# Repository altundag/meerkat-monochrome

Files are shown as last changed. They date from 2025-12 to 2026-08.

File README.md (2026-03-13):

# Meerkat Monochrome

Meerkat Monochrome is a monochrome camera project that I started as a hobby. This repository contains the complete design, including PCB layouts, firmware, and supporting tools. The camera hardware consists of:
- an MT9M001C12STM monochrome image sensor
- an RP2354A used as the camera's processing and control unit
- an APS6404L-3SQR QSPI PSRAM for the frame buffer
- an FM25L16B F-RAM to permanently store data (e.g., the frame count)

The image sensor itself is capable of operating at clock speeds up to 48 MHz. However, in this design the pixel clock is set to 6.5 MHz, because the PSRAM frame buffer cannot accept data at higher throughput. This also means the project doesn't require a high-speed PCB, which makes my job easier since I'm not a professional PCB designer.
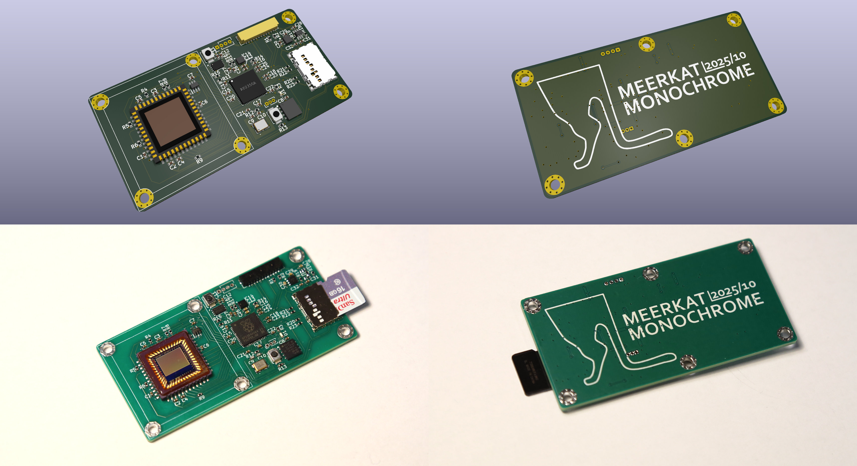
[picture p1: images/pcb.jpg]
PCB Prototype Image PCB Prototype


The PCB design has tiny 0402 components. They require a steady hand, but you can still assemble the board manually using a reflow oven.

The firmware is written entirely in Rust and is actively under development. When this project started, there was no Rust library available to interface with the MT9M001C12STM sensor, so this repository also incleads a tool that automatically generates a library from a JSON sensor description file. Please see the `mt9m001` project for details.

# Examples

An example image taken during prototype PCB testing:

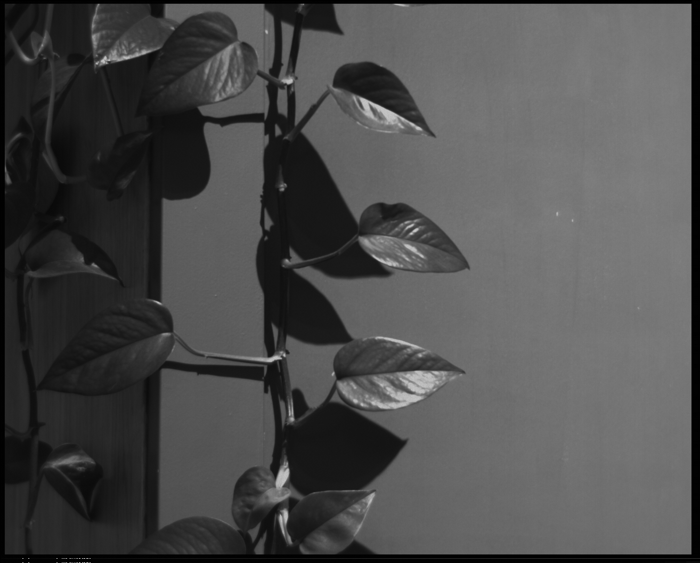
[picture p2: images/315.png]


If you have a close look at the image above, you can see the fixed pattern noise. It is more visible when the sensor is evenly exposed to light.

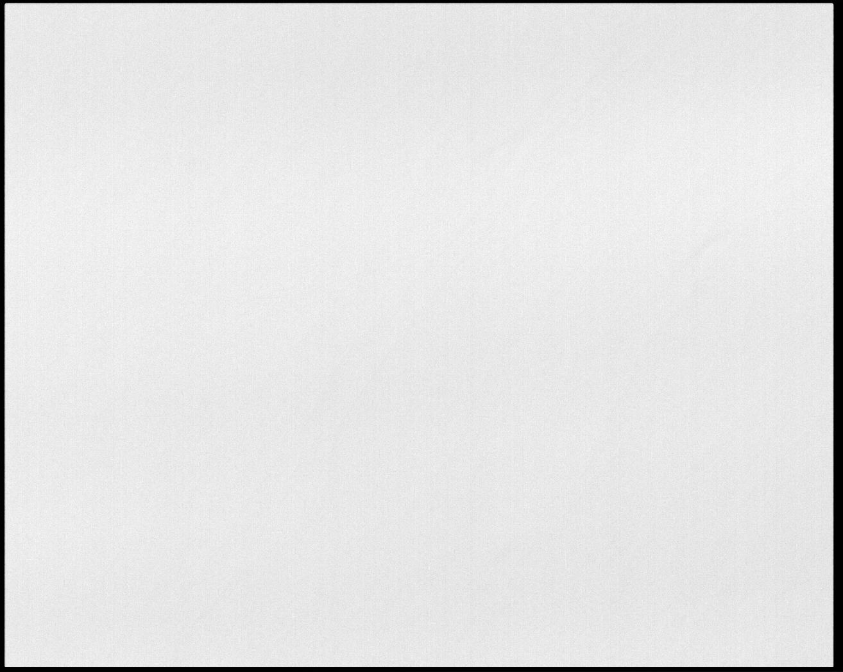
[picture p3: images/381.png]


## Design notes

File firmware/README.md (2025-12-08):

# Meerkat Firmware

## Build and Run

To build and run the firmware, first install Rust, then add the `thumbv8m.main-none-eabihf` target:

```shell
rustup target add thumbv8m.main-none-eabihf
```

NExt, make the [picotool executable](https://github.com/raspberrypi/pico-sdk-tools/releases) available in your system's environment path. Once that's done, run:

```shell
cargo run --release
```

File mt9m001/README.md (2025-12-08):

# MT9M001C12STM

An automatically generated Rust library to control MT9M001C12STM image sensors.

## Generation

Run the following command to generate the library from the JSON description file.

```shell
python .\generator.py .\mt9m001.json .\src\lib.rs
```

The generator implementation is primitive and may produce code with minor `clippy` issues. Run the following command to automatically fix them.

```shell
cargo clippy --fix --allow-dirty
```

## Sensor Description File

The expected sensor description file is a simple JSON file that:
- contains the sensor name and address
- list the registers, their documentation, and their bit-fields (if any)

See the `mt9m001.json` file for an examples.

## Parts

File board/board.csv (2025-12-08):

Reference | Qty | Value | DNP | Exclude from BOM | Exclude from Board | Footprint | Datasheet
C1,C2,C3,C4,C5,C6,C7,C8,C11,C15,C18,C19,C20,C21,C22,C23,C24,C25,C26,C27,C31 | 21 | 100n |  |  |  | Capacitor_SMD:C_0402_1005Metric | ~
C9,C10 | 2 | 15p |  |  |  | Capacitor_SMD:C_0402_1005Metric | ~
C12,C32 | 2 | 1u |  |  |  | Capacitor_SMD:C_0402_1005Metric | ~
C13,C14 | 2 | 4.7u |  |  |  | components:C_0402_1005Metric_small_pads | ~
C16,C17,C28,C29,C30 | 5 | 4.7u |  |  |  | Capacitor_SMD:C_0402_1005Metric | ~
D1 | 1 | LED |  |  |  | LED_SMD:LED_0402_1005Metric | ~
D2 | 1 | LM66100DCKR |  |  |  | components:LM66100DCKR | http://www.ti.com/lit/gpn/LM66100
H1,H2 | 2 | MountingHole_Pad |  | Excluded from BOM |  | MountingHole:MountingHole_2.2mm_M2_Pad_Via | ~
IC1 | 1 | NC7SZ11P6X |  |  |  | components:NC7SZ11P6X | https://www.onsemi.com/pub/Collateral/NC7SZ11-D.PDF
IC2 | 1 | FM25L16B-DG |  |  |  | components:FM25L16B-DG | http://www.cypress.com/file/136516/download
IC3 | 1 | NCP189CMTW330TAG |  |  |  | components:NCP189CMTW330TAG | https://www.onsemi.com/pub/Collateral/NCP189-D.PDF
J1 | 1 | USB |  |  |  | Connector_PinHeader_1.27mm:PinHeader_1x04_P1.27mm_Vertical | ~
J2 | 1 | Conn_01x12 |  |  |  | Connector_Hirose:Hirose_DF52-12S-0.8H_1x12-1MP_P0.80mm_Horizontal | ~
J3 | 1 | Conn_01x03 |  |  |  | Connector_PinHeader_1.00mm:PinHeader_1x03_P1.00mm_Vertical | ~
J4 | 1 | MEM2085-00-115-00-A |  |  |  | components:MEM20850011500A | https://gct.co/files/drawings/mem2085.pdf
L1 | 1 | 3.3u |  |  |  | components:AOTA-B201610S3R3-101-T | ~
M1 | 1 | ~ |  |  |  | components:c-mount-03
R1,R4,R5,R6,R18 | 5 | 10K |  |  |  | Resistor_SMD:R_0402_1005Metric | ~
R2 | 1 | 100R |  |  |  | Resistor_SMD:R_0402_1005Metric | ~
R3 | 1 | 65R |  |  |  | Resistor_SMD:R_0402_1005Metric | ~
R7,R8 | 2 | 1.5K |  |  |  | Resistor_SMD:R_0402_1005Metric | ~
R9 | 1 | 30R |  |  |  | Resistor_SMD:R_0402_1005Metric | ~
R11 | 1 | 100K |  |  |  | components:R_0402_1005Metric_small_pads | ~
R12,R13 | 2 | 1k |  |  |  | Resistor_SMD:R_0402_1005Metric | ~
R14 | 1 | 33 |  |  |  | Resistor_SMD:R_0402_1005Metric | ~
R15 | 1 | 1k |  |  |  | components:R_0402_1005Metric_small_pads | ~
R16,R17 | 2 | 27 |  |  |  | Resistor_SMD:R_0402_1005Metric | ~
R19 | 1 | 0R |  |  |  | components:R_0402_1005Metric_small_pads | ~
R20,R21,R22,R23 | 4 | 10K |  |  |  | components:R_0402_1005Metric_small_pads | ~
SW1,SW2 | 2 | SW_Push |  |  |  | Button_Switch_SMD:SW_SPST_B3U-1000P | ~
U1 | 1 | MT9M001C12STM |  |  |  | components:MT9M001C12STM
U2 | 1 | APS6404L-3SQR-ZR |  |  |  | Package_SON:Winbond_USON-8-1EP_3x2mm_P0.5mm_EP0.2x1.6mm | https://www.mouser.com/datasheet/2/1127/APM_PSRAM_QSPI_APS6404L_3SQR_v2_3_PKG-1954826.pdf
U3 | 1 | RP2350_60QFN |  |  |  | components:RP2350-QFN-60-1EP_7x7_P0.4mm_EP3.4x3.4mm_ThermalVias
Y1 | 1 | ABM8-272-T3 |  |  |  | components:ABM8272T3 | ~

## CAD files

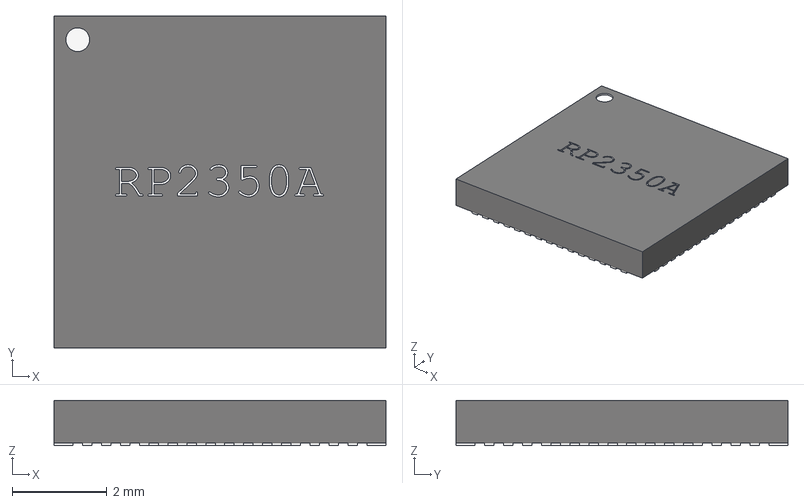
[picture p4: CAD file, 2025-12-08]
board/components/RP2350-QFN-60.step
7.00 x 7.00 x 0.95 mm

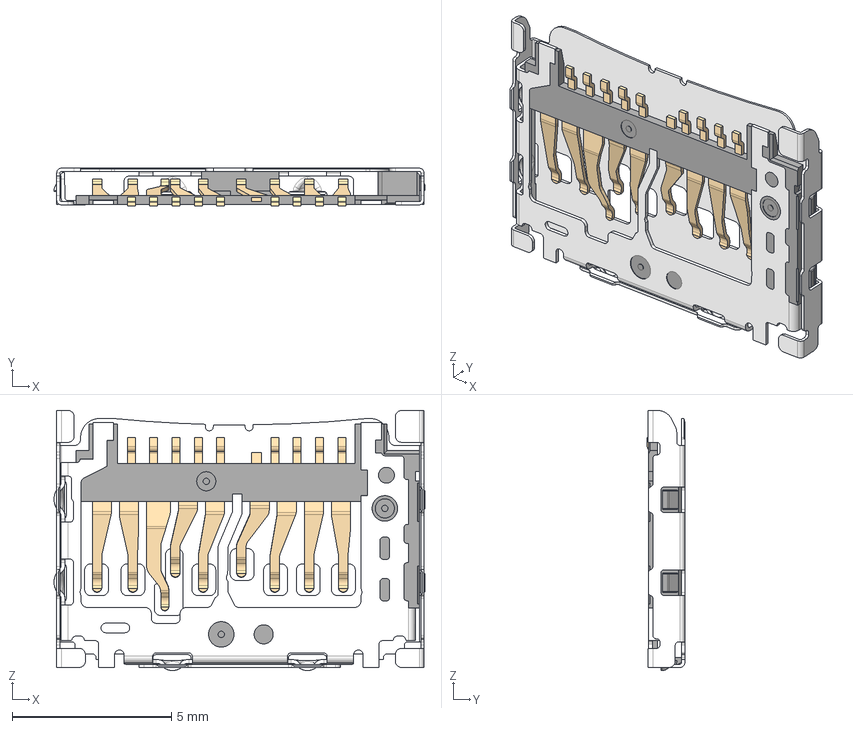
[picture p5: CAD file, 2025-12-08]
board/components/MEM2085-00-115-00-A.stp
11.6 x 1.18 x 8.16 mm
MEM2085-00-115-00-A_PART3
MEM2085-00-115-00-A_PART2
MEM2085-00-115-00-A_PART1

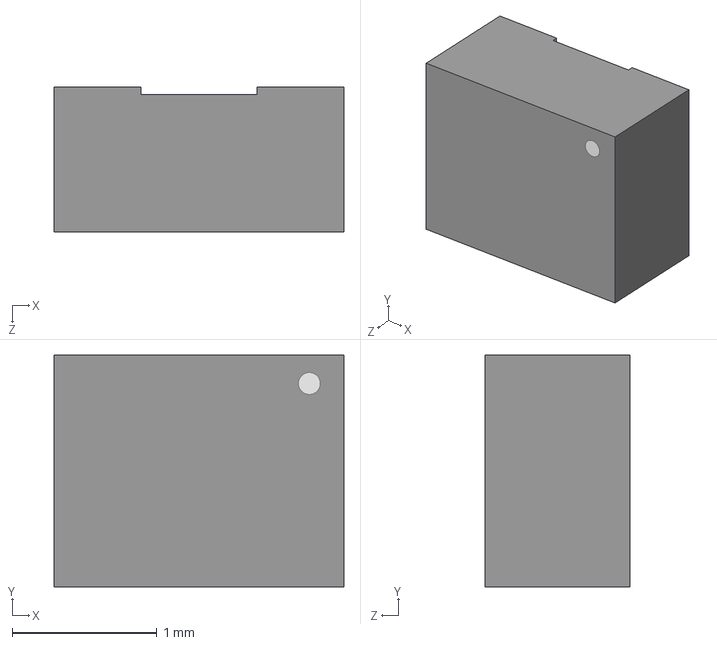
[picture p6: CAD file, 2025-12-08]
board/components/AOTA-B201610S3R3-101-T.stp
2.00 x 1.60 x 1.00 mm

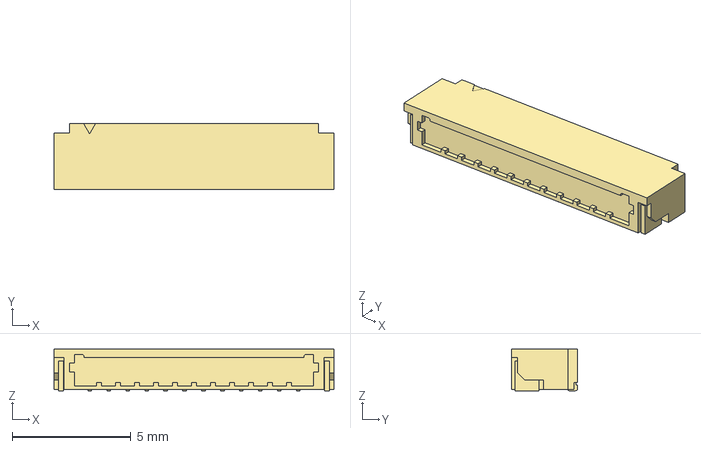
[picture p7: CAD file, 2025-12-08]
board/components/DF52-12S-0.8H_21_.stp
11.8 x 2.77 x 1.75 mm

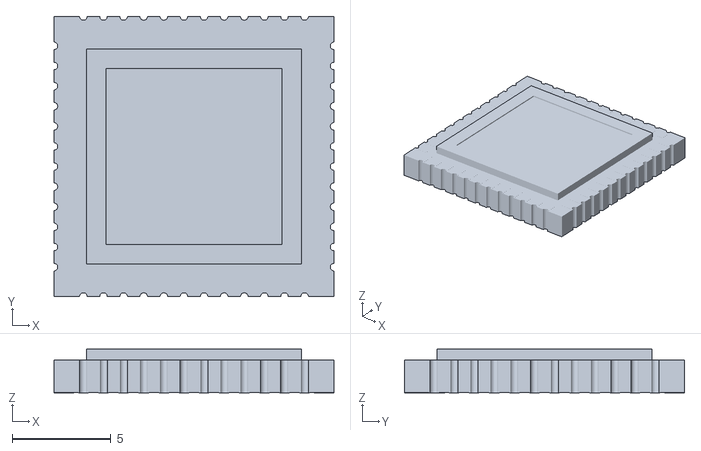
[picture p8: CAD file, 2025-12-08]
board/components/MT9M001C12STM.obj
14.2 x 14.2 x 2.21

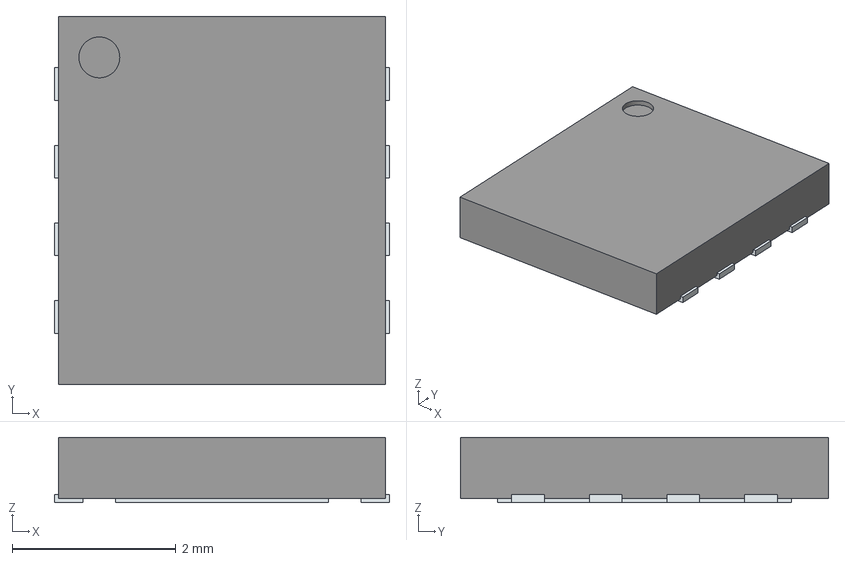
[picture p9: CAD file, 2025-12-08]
board/components/FM25L16B-DG.stp
4.10 x 4.50 x 0.8 mm
ThermalPin
PinsArrayLR

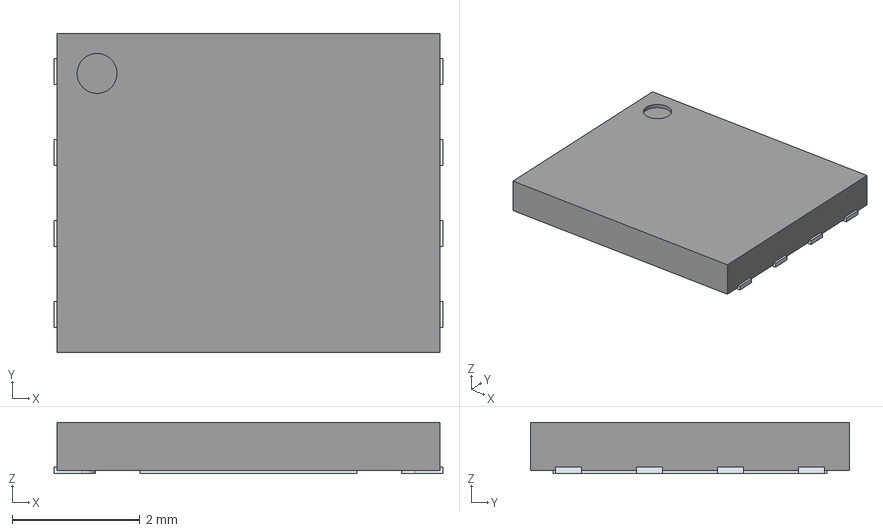
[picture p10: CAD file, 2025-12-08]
board/components/W25Q128JVPIQ.stp
6.10 x 5.00 x 0.8 mm
ThermalPin
PinsArrayLR

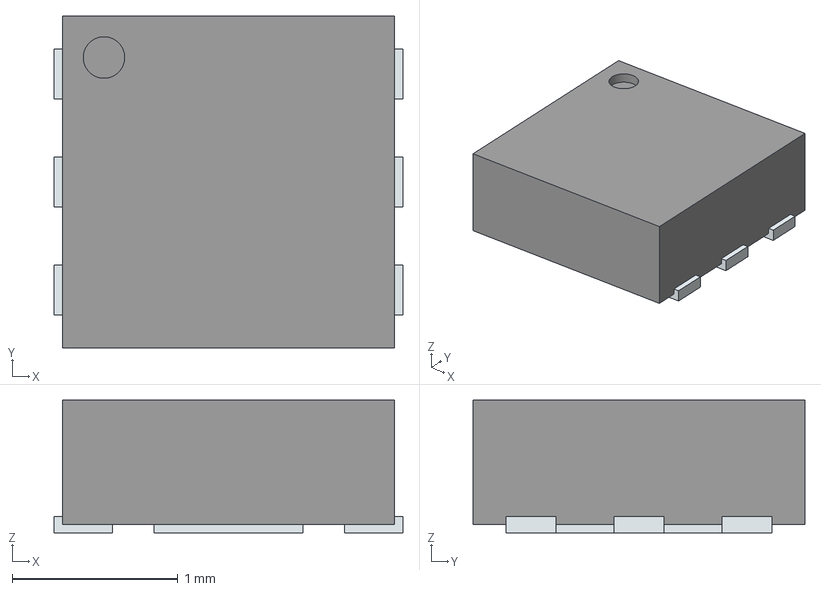
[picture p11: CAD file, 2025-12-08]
board/components/NCP189CMTW330TAG.stp
2.10 x 2.00 x 0.8 mm
ThermalPin
PinsArrayLR

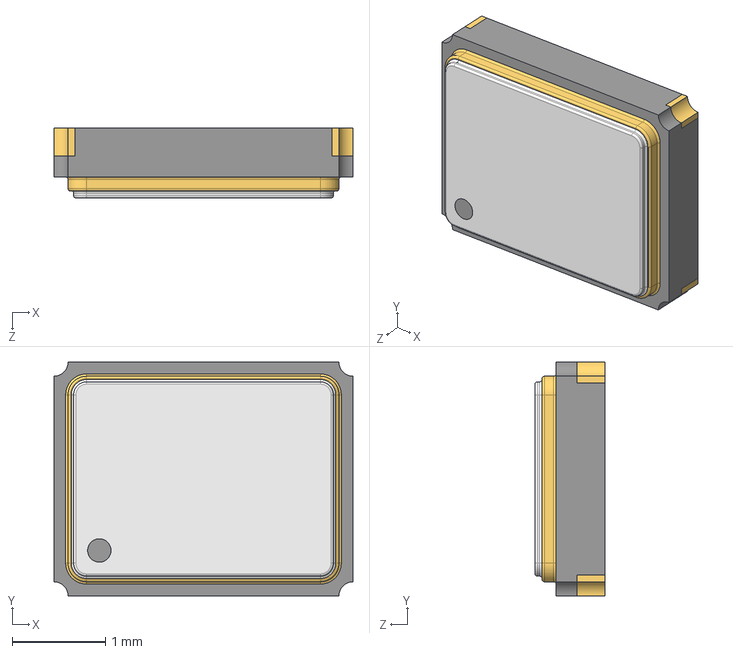
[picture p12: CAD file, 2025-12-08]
board/components/ABM8-272-T3.stp
3.20 x 2.50 x 0.75 mm

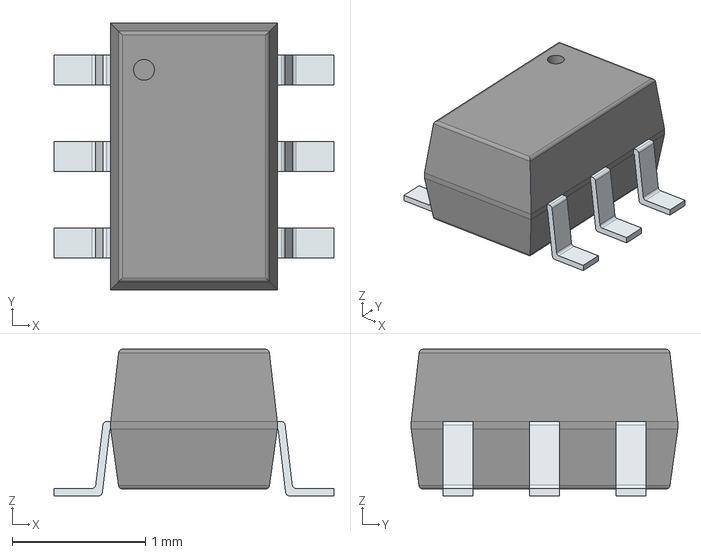
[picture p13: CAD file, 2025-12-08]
board/components/NC7SZ11P6X.stp
2.10 x 2.00 x 1.10 mm
PinsArrayLR

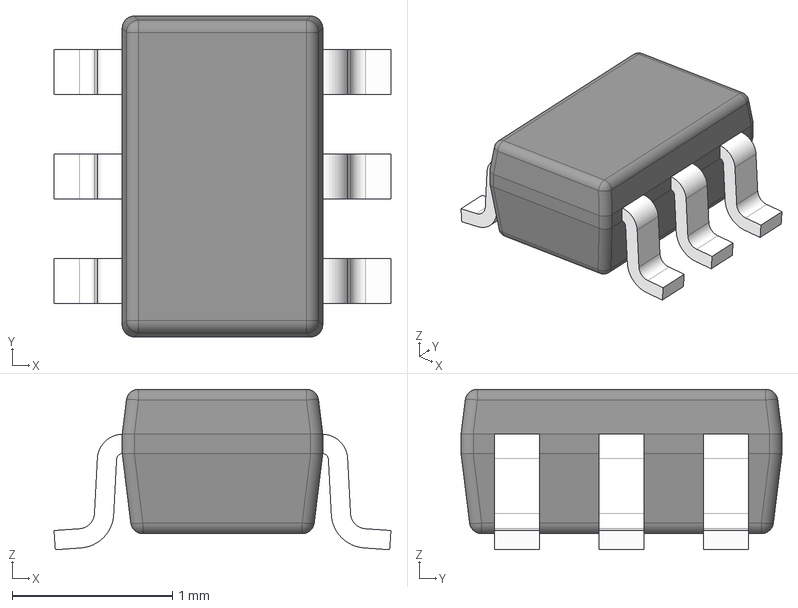
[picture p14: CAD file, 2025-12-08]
board/components/LM66100DCKR.stp
2.10 x 2.00 x 1.00 mm
BODY-SOT
LEAD-SOT x 6
PIN1-ID

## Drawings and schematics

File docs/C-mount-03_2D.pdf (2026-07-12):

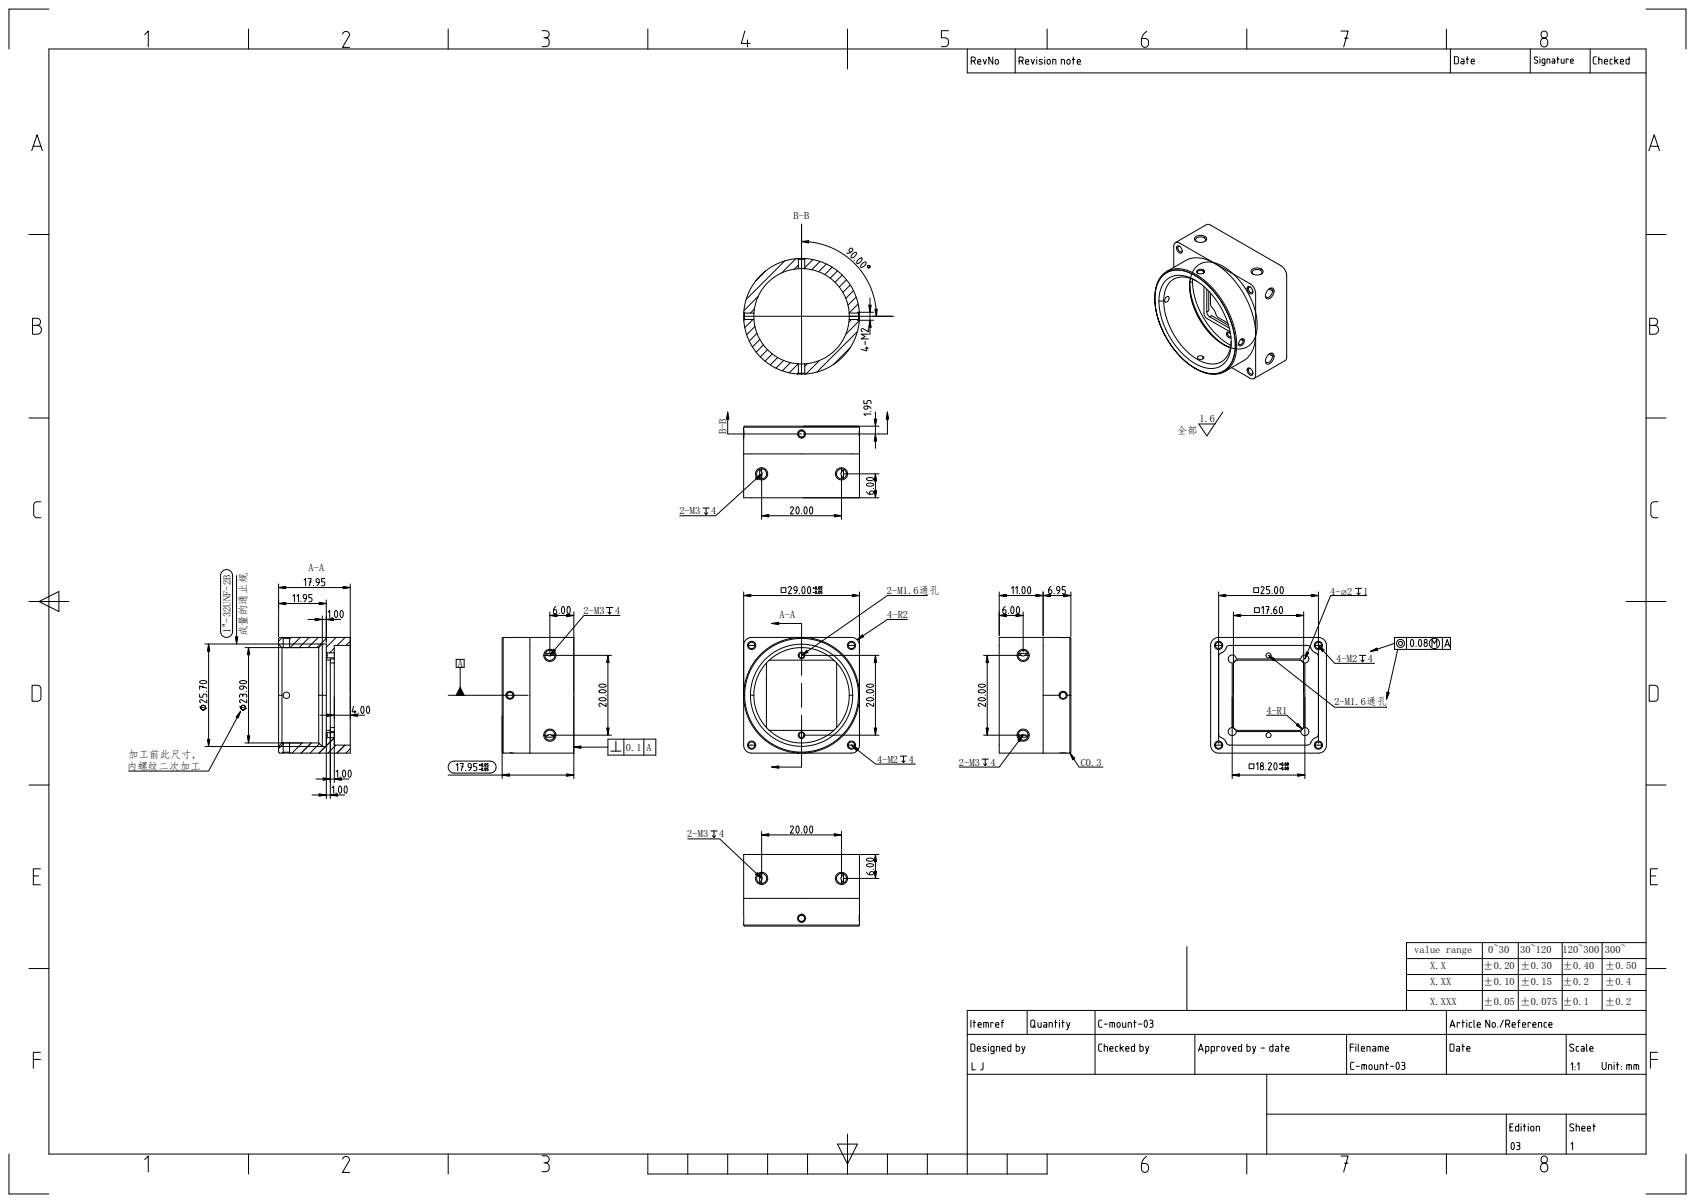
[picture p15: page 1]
A 加工前此尺寸, 内螺纹二次加工; 1"-32UNF-2B 成量的通止规

value range | 0~30 | 30~120 | 120~300 | 300~
X.X | ±0.20 | ±0.30 | ±0.40 | ±0.50
X.XX | ±0.10 | ±0.15 | ±0.2 | ±0.4
X.XXX | ±0.05 | ±0.075 | ±0.1 | ±0.2

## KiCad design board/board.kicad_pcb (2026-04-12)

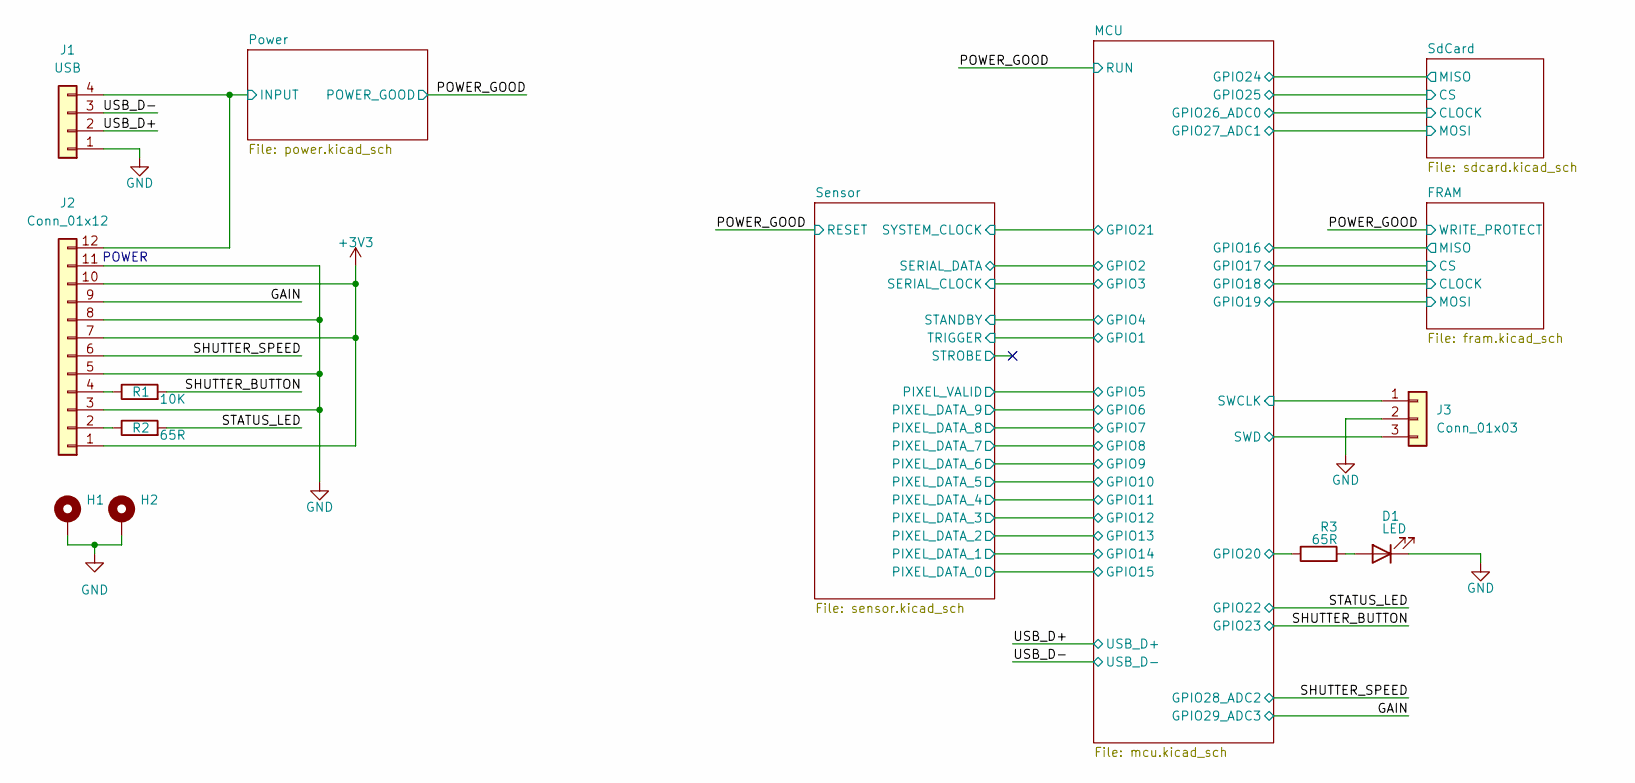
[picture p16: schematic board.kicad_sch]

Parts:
D1: LED; LED_0402_1005Metric
H1, H2: MountingHole_Pad; MountingHole_2.2mm_M2_Pad_Via
J1: USB; PinHeader_1x04_P1.27mm_Vertical
J2: Conn_01x12; Hirose_DF52-12S-0.8H_1x12-1MP_P0.80mm_Horizontal
J3: Conn_01x03; PinHeader_1x03_P1.00mm_Vertical
R1: 10K; R_0402_1005Metric
R2, R3: 65R; R_0402_1005Metric

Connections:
+3V3: J2.1, J2.7, J2.10; also elsewhere on the board
/GAIN: J2.9; also elsewhere on the board
/MCU/GPIO20: R3.1; also elsewhere on the board
/MCU/SWCLK: J3.1; also elsewhere on the board
/MCU/SWD: J3.3; also elsewhere on the board
/Power/INPUT: J1.4, J2.12; also elsewhere on the board
/SHUTTER_BUTTON: R1.2; also elsewhere on the board
/SHUTTER_SPEED: J2.6; also elsewhere on the board
/STATUS_LED: R2.2; also elsewhere on the board
/USB_D+: J1.2; also elsewhere on the board
/USB_D-: J1.3; also elsewhere on the board
GND: D1.1 (K), H1.1, H2.1, J1.1, J2.3, J2.5, J2.8, J2.11, J3.2; also elsewhere on the board
unnamed: D1.2 (A), R3.2
unnamed: J2.2, R2.1
unnamed: J2.4, R1.1

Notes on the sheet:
POWER

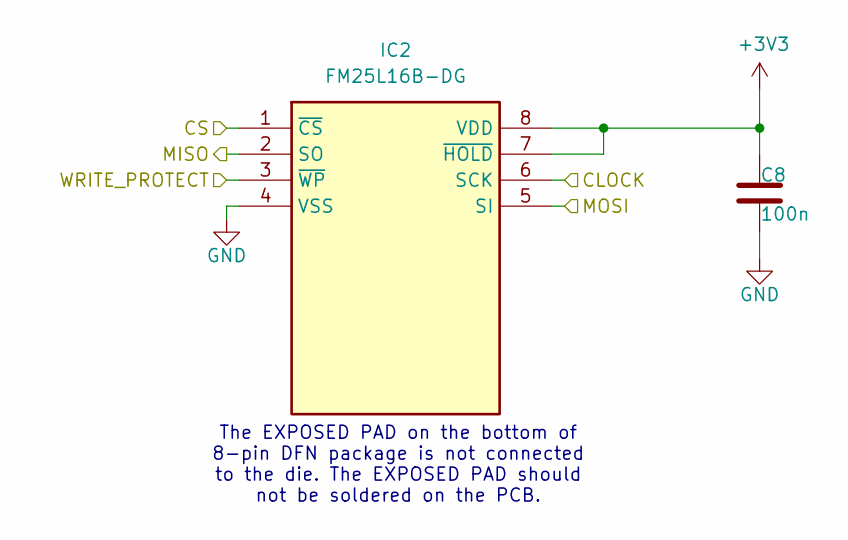
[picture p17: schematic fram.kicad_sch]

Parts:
C8: 100n; C_0402_1005Metric
IC2: FM25L16B-DG; Mouser Part Number 877-FM25L16B-DG

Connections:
+3V3: C8.2, IC2.7 (~HOLD), IC2.8 (VDD); also elsewhere on the board
/FRAM/CLOCK: IC2.6 (SCK); also elsewhere on the board
/FRAM/CS: IC2.1 (~CS); also elsewhere on the board
/FRAM/MISO: IC2.2 (SO); also elsewhere on the board
/FRAM/MOSI: IC2.5 (SI); also elsewhere on the board
/POWER_GOOD: IC2.3 (~WP); also elsewhere on the board
GND: C8.1, IC2.4 (VSS); also elsewhere on the board

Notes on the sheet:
The EXPOSED PAD on the bottom of 8-pin DFN package is not connected to the die. The EXPOSED PAD should not be soldered on the PCB.

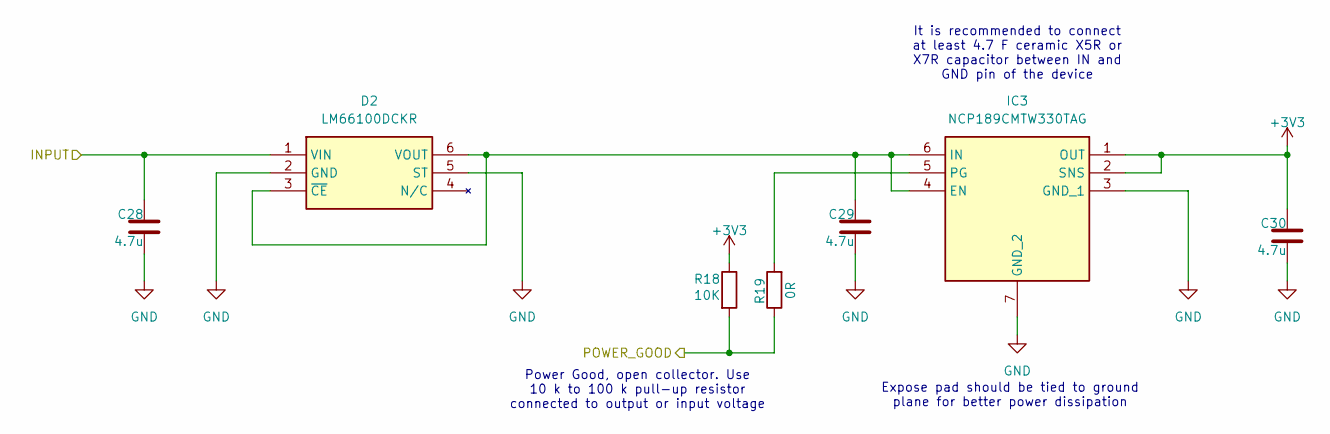
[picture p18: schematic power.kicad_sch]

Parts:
C28, C29, C30: 4.7u; C_0402_1005Metric
D2: LM66100DCKR; Mouser Part Number 595-LM66100DCKR
IC3: NCP189CMTW330TAG; Mouser Part Number 863-NCP189CMTW330TAG
R18: 10K; R_0402_1005Metric
R19: 0R; R_0402_1005Metric_small_pads

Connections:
+3V3: C30.2, IC3.1 (OUT), IC3.2 (SNS), R18.1; also elsewhere on the board
/POWER_GOOD: R18.2, R19.1; also elsewhere on the board
/Power/INPUT: C28.2, D2.1 (VIN); also elsewhere on the board
GND: C28.1, C29.1, C30.1, D2.2 (GND), D2.5 (ST), IC3.3 (GND_1), IC3.7 (GND_2); also elsewhere on the board
unnamed: C29.2, D2.3 (~CE), D2.6 (VOUT), IC3.4 (EN), IC3.6 (IN)
unnamed: IC3.5 (PG), R19.2

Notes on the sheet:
Power Good, open collector. Use 10 k to 100 k pull−up resistor connected to output or input voltage
It is recommended to connect at least 4.7 F ceramic X5R or X7R capacitor between IN and GND pin of the device
Expose pad should be tied to ground plane for better power dissipation

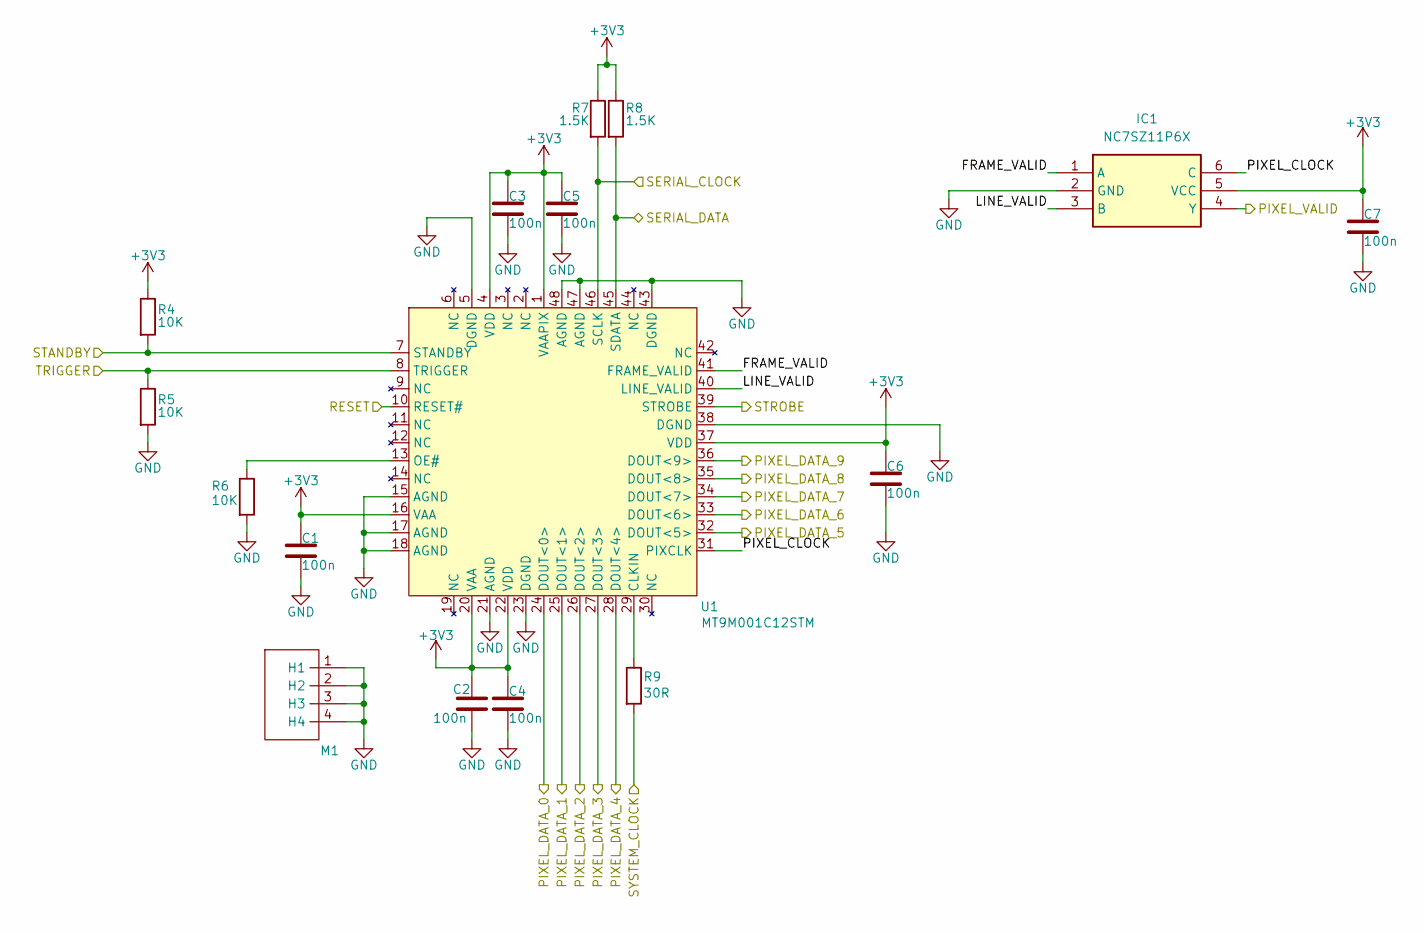
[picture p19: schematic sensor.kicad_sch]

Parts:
C1, C2, C3, C4, C5, C6, C7: 100n; C_0402_1005Metric
IC1: NC7SZ11P6X; Mouser Part Number 512-NC7SZ11P6X
M1: c-mount-03
R4, R5, R6: 10K; R_0402_1005Metric
R7, R8: 1.5K; R_0402_1005Metric
R9: 30R; R_0402_1005Metric
U1: MT9M001C12STM

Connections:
+3V3: C1.2, C2.2, C3.2, C4.2, C5.2, C6.2, C7.2, IC1.5 (VCC), R4.1, R7.1, R8.1, U1.1 (VAAPIX), U1.4 (VDD), U1.16 (VAA), U1.20 (VAA), U1.22 (VDD), U1.37 (VDD); also elsewhere on the board
/MCU/GPIO1: R5.1, U1.8 (TRIGGER); also elsewhere on the board
/MCU/GPIO2: R8.2, U1.45 (SDATA); also elsewhere on the board
/MCU/GPIO3: R7.2, U1.46 (SCLK); also elsewhere on the board
/MCU/GPIO4: R4.2, U1.7 (STANDBY); also elsewhere on the board
/MCU/GPIO5: IC1.4 (Y); also elsewhere on the board
/MCU/GPIO6: U1.36 (DOUT<9>); also elsewhere on the board
/MCU/GPIO7: U1.35 (DOUT<8>); also elsewhere on the board
/MCU/GPIO8: U1.34 (DOUT<7>); also elsewhere on the board
/MCU/GPIO9: U1.33 (DOUT<6>); also elsewhere on the board
/MCU/GPIO10: U1.32 (DOUT<5>); also elsewhere on the board
/MCU/GPIO11: U1.28 (DOUT<4>); also elsewhere on the board
/MCU/GPIO12: U1.27 (DOUT<3>); also elsewhere on the board
/MCU/GPIO13: U1.26 (DOUT<2>); also elsewhere on the board
/MCU/GPIO14: U1.25 (DOUT<1>); also elsewhere on the board
/MCU/GPIO15: U1.24 (DOUT<0>); also elsewhere on the board
/MCU/GPIO21: R9.2; also elsewhere on the board
/POWER_GOOD: U1.10 (RESET#); also elsewhere on the board
/Sensor/FRAME_VALID: IC1.1 (A), U1.41 (FRAME_VALID)
/Sensor/LINE_VALID: IC1.3 (B), U1.40 (LINE_VALID)
/Sensor/PIXEL_CLOCK: IC1.6 (C), U1.31 (PIXCLK)
/Sensor/STROBE: U1.39 (STROBE)
GND: C1.1, C2.1, C3.1, C4.1, C5.1, C6.1, C7.1, IC1.2 (GND), M1.1 (H1), M1.2 (H2), M1.3 (H3), M1.4 (H4), R5.2, R6.2, U1.5 (DGND), U1.15 (AGND), U1.17 (AGND), U1.18 (AGND), U1.21 (AGND), U1.23 (DGND), U1.38 (DGND), U1.43 (DGND), U1.47 (AGND), U1.48 (AGND); also elsewhere on the board
unnamed: R9.1, U1.29 (CLKIN)
unnamed: R6.1, U1.13 (OE#)

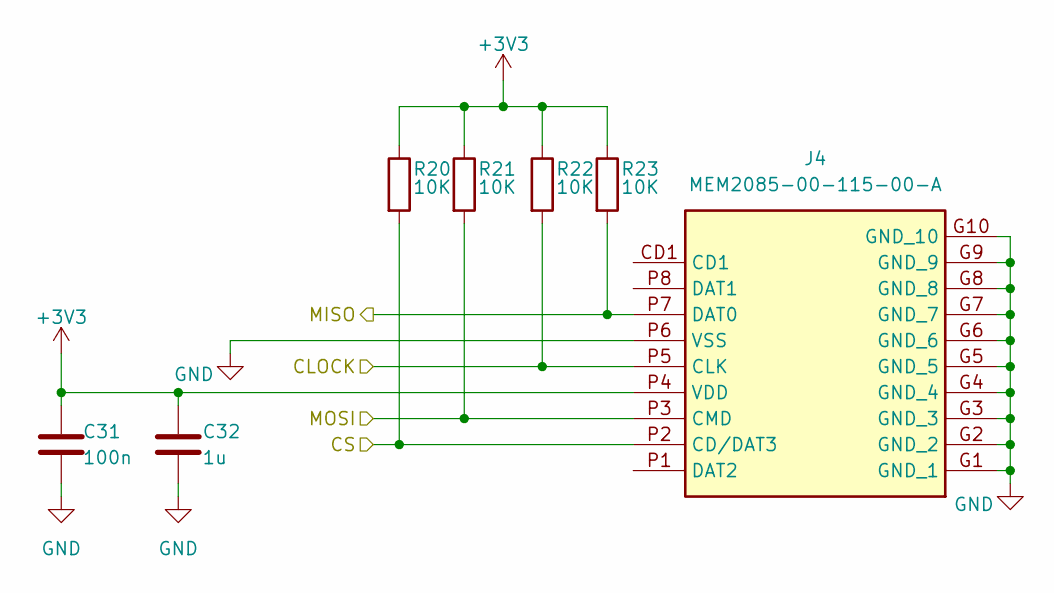
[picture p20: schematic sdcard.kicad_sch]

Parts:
C31: 100n; C_0402_1005Metric
C32: 1u; C_0402_1005Metric
J4: MEM2085-00-115-00-A; MEM20850011500A; Mouser Part Number 640-MEM20850011500A
R20, R21, R22, R23: 10K; R_0402_1005Metric_small_pads

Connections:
+3V3: C31.2, C32.2, J4.P4 (VDD), R20.1, R21.1, R22.1, R23.1; also elsewhere on the board
/MCU/GPIO24: J4.P7 (DAT0), R23.2; also elsewhere on the board
/MCU/GPIO25: J4.P2 (CD/DAT3), R20.2; also elsewhere on the board
/MCU/GPIO26_ADC0: J4.P5 (CLK), R22.2; also elsewhere on the board
/MCU/GPIO27_ADC1: J4.P3 (CMD), R21.2; also elsewhere on the board
GND: C31.1, C32.1, J4.G1 (GND_1), J4.G2 (GND_2), J4.G3 (GND_3), J4.G4 (GND_4), J4.G5 (GND_5), J4.G6 (GND_6), J4.G7 (GND_7), J4.G8 (GND_8), J4.G9 (GND_9), J4.G10 (GND_10), J4.P6 (VSS); also elsewhere on the board

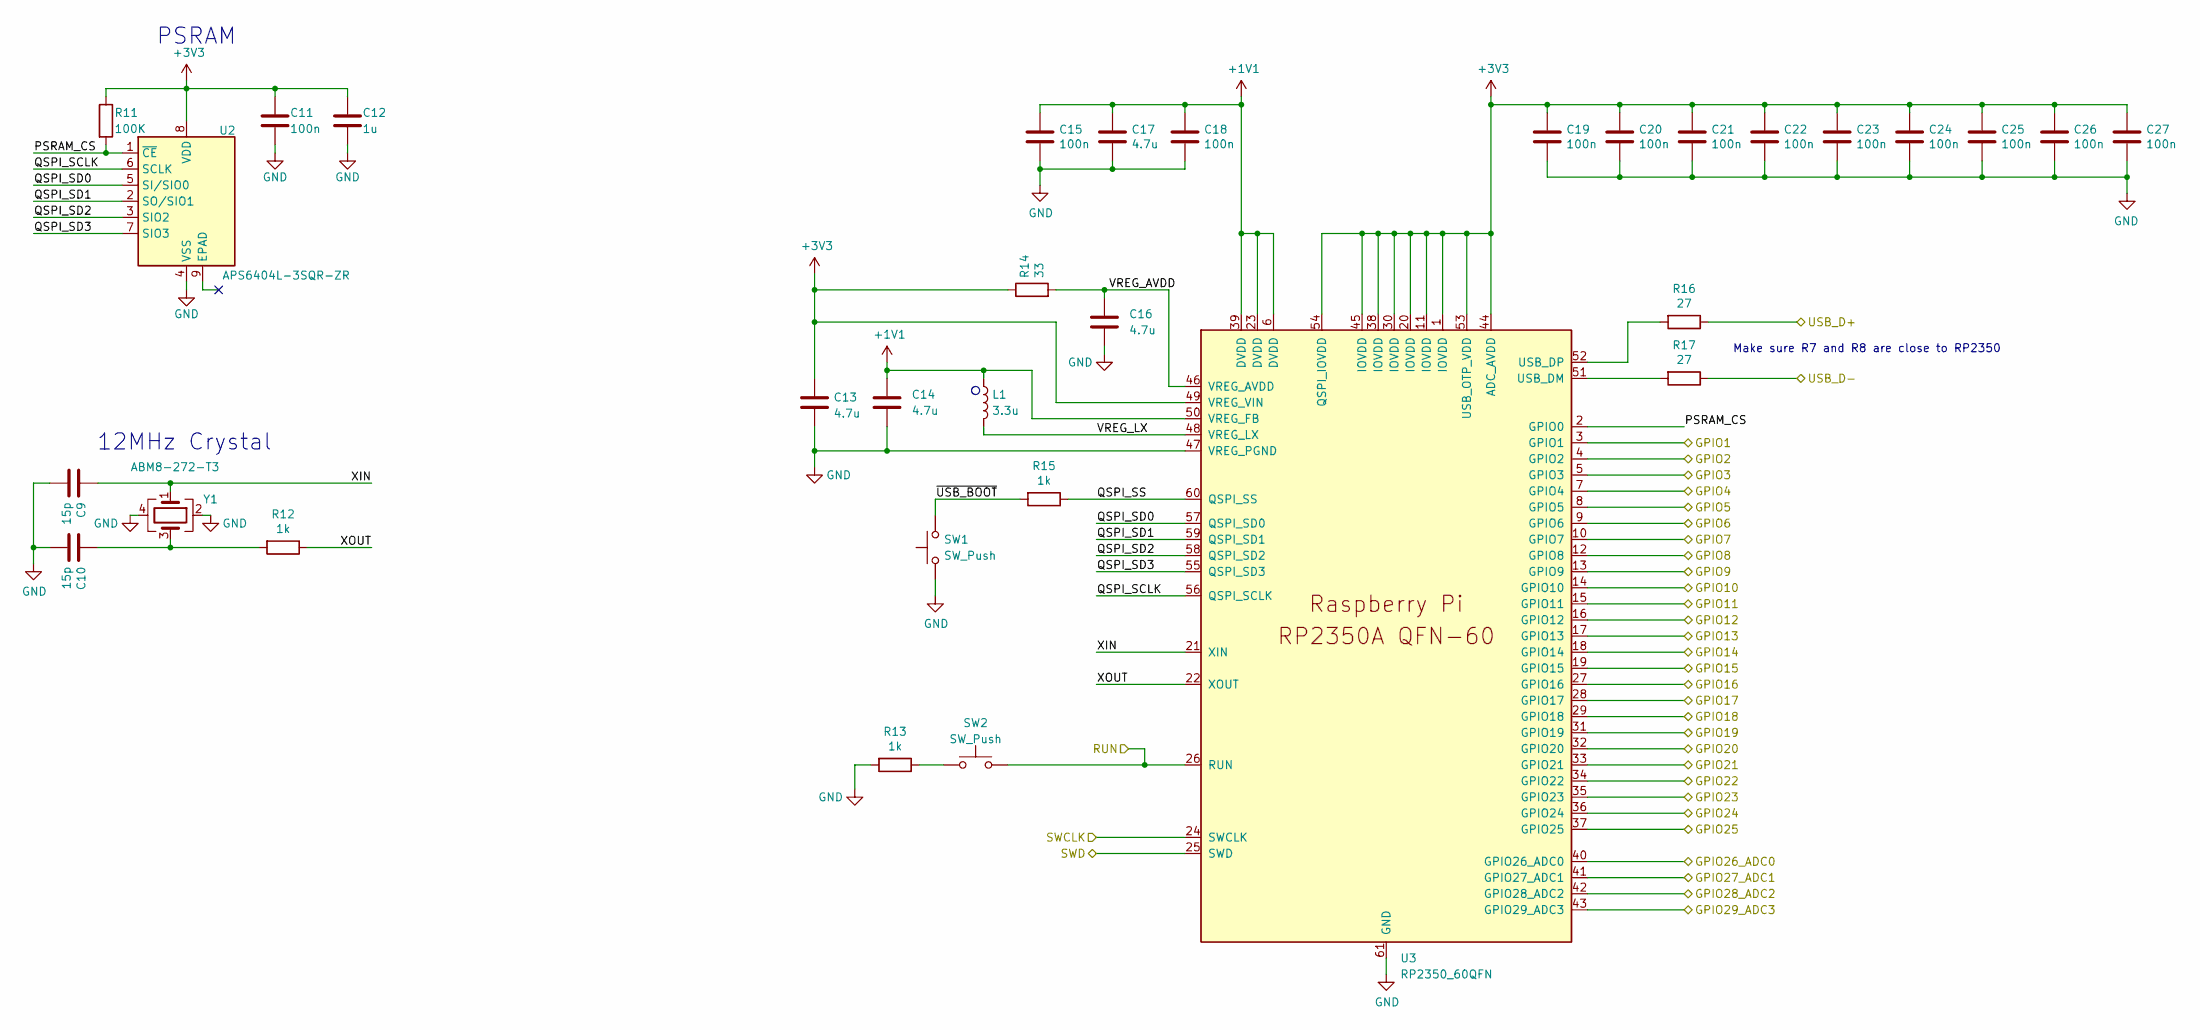
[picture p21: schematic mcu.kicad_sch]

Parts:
C9, C10: 15p; C_0402_1005Metric
C11, C15, C18, C19, C20, C21, C22, C23, C24, C25, C26, C27: 100n; C_0402_1005Metric
C12: 1u; C_0402_1005Metric
C13, C14: 4.7u; C_0402_1005Metric_small_pads
C16, C17: 4.7u; C_0402_1005Metric
L1: 3.3u; AOTA-B201610S3R3-101-T
R11: 100K; R_0402_1005Metric_small_pads
R12, R13: 1k; R_0402_1005Metric
R14: 33; R_0402_1005Metric
R15: 1k; R_0402_1005Metric_small_pads
R16, R17: 27; R_0402_1005Metric
SW1, SW2: SW_Push; SW_SPST_B3U-1000P
U2: APS6404L-3SQR-ZR; Winbond_USON-8-1EP_3x2mm_P0.5mm_EP0.2x1.6mm
U3: RP2350_60QFN; RP2350-QFN-60-1EP_7x7_P0.4mm_EP3.4x3.4mm_ThermalVias
Y1: ABM8-272-T3; ABM8272T3

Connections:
+1V1: C14.1, C15.1, C17.1, C18.1, L1.1, U3.6 (DVDD), U3.23 (DVDD), U3.39 (DVDD), U3.50 (VREG_FB)
+3V3: C11.2, C12.2, C13.1, C19.1, C20.1, C21.1, C22.1, C23.1, C24.1, C25.1, C26.1, C27.1, R11.1, R14.1, U2.8 (VDD), U3.1 (IOVDD), U3.11 (IOVDD), U3.20 (IOVDD), U3.30 (IOVDD), U3.38 (IOVDD), U3.44 (ADC_AVDD), U3.45 (IOVDD), U3.49 (VREG_VIN), U3.53 (USB_OTP_VDD), U3.54 (QSPI_IOVDD); also elsewhere on the board
/FRAM/CLOCK: U3.29 (GPIO18); also elsewhere on the board
/FRAM/CS: U3.28 (GPIO17); also elsewhere on the board
/FRAM/MISO: U3.27 (GPIO16); also elsewhere on the board
/FRAM/MOSI: U3.31 (GPIO19); also elsewhere on the board
/GAIN: U3.43 (GPIO29_ADC3); also elsewhere on the board
/MCU/GPIO1: U3.3 (GPIO1); also elsewhere on the board
/MCU/GPIO2: U3.4 (GPIO2); also elsewhere on the board
/MCU/GPIO3: U3.5 (GPIO3); also elsewhere on the board
/MCU/GPIO4: U3.7 (GPIO4); also elsewhere on the board
/MCU/GPIO5: U3.8 (GPIO5); also elsewhere on the board
/MCU/GPIO6: U3.9 (GPIO6); also elsewhere on the board
/MCU/GPIO7: U3.10 (GPIO7); also elsewhere on the board
/MCU/GPIO8: U3.12 (GPIO8); also elsewhere on the board
/MCU/GPIO9: U3.13 (GPIO9); also elsewhere on the board
/MCU/GPIO10: U3.14 (GPIO10); also elsewhere on the board
/MCU/GPIO11: U3.15 (GPIO11); also elsewhere on the board
/MCU/GPIO12: U3.16 (GPIO12); also elsewhere on the board
/MCU/GPIO13: U3.17 (GPIO13); also elsewhere on the board
/MCU/GPIO14: U3.18 (GPIO14); also elsewhere on the board
/MCU/GPIO15: U3.19 (GPIO15); also elsewhere on the board
/MCU/GPIO20: U3.32 (GPIO20); also elsewhere on the board
/MCU/GPIO21: U3.33 (GPIO21); also elsewhere on the board
/MCU/GPIO24: U3.36 (GPIO24); also elsewhere on the board
/MCU/GPIO25: U3.37 (GPIO25); also elsewhere on the board
/MCU/GPIO26_ADC0: U3.40 (GPIO26_ADC0); also elsewhere on the board
/MCU/GPIO27_ADC1: U3.41 (GPIO27_ADC1); also elsewhere on the board
/MCU/PSRAM_CS: R11.2, U2.1 (~CE), U3.2 (GPIO0)
/MCU/QSPI_SCLK: U2.6 (SCLK), U3.56 (QSPI_SCLK)
/MCU/QSPI_SD0: U2.5 (SI/SIO0), U3.57 (QSPI_SD0)
/MCU/QSPI_SD1: U2.2 (SO/SIO1), U3.59 (QSPI_SD1)
/MCU/QSPI_SD2: U2.3 (SIO2), U3.58 (QSPI_SD2)
/MCU/QSPI_SD3: U2.7 (SIO3), U3.55 (QSPI_SD3)
/MCU/QSPI_SS: R15.1, U3.60 (QSPI_SS)
/MCU/SWCLK: U3.24 (SWCLK); also elsewhere on the board
/MCU/SWD: U3.25 (SWD); also elsewhere on the board
/MCU/VREG_AVDD: C16.1, R14.2, U3.46 (VREG_AVDD)
/MCU/VREG_LX: L1.2, U3.48 (VREG_LX)
/MCU/XIN: C9.1, U3.21 (XIN), Y1.1
/MCU/XOUT: R12.1, U3.22 (XOUT)
/MCU/~USB_BOOT: R15.2, SW1.2
/POWER_GOOD: SW2.2, U3.26 (RUN); also elsewhere on the board
/SHUTTER_BUTTON: U3.35 (GPIO23); also elsewhere on the board
/SHUTTER_SPEED: U3.42 (GPIO28_ADC2); also elsewhere on the board
/STATUS_LED: U3.34 (GPIO22); also elsewhere on the board
/USB_D+: R16.1; also elsewhere on the board
/USB_D-: R17.1; also elsewhere on the board
GND: C9.2, C10.2, C11.1, C12.1, C13.2, C14.2, C15.2, C16.2, C17.2, C18.2, C19.2, C20.2, C21.2, C22.2, C23.2, C24.2, C25.2, C26.2, C27.2, R13.2, SW1.1, U2.4 (VSS), U3.47 (VREG_PGND), U3.61 (GND), Y1.2, Y1.4; also elsewhere on the board
unnamed: C10.1, R12.2, Y1.3
unnamed: R13.1, SW2.1
unnamed: R17.2, U3.51 (USB_DM)
unnamed: R16.2, U3.52 (USB_DP)

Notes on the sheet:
Make sure R7 and R8 are close to RP2350
PSRAM
12MHz Crystal

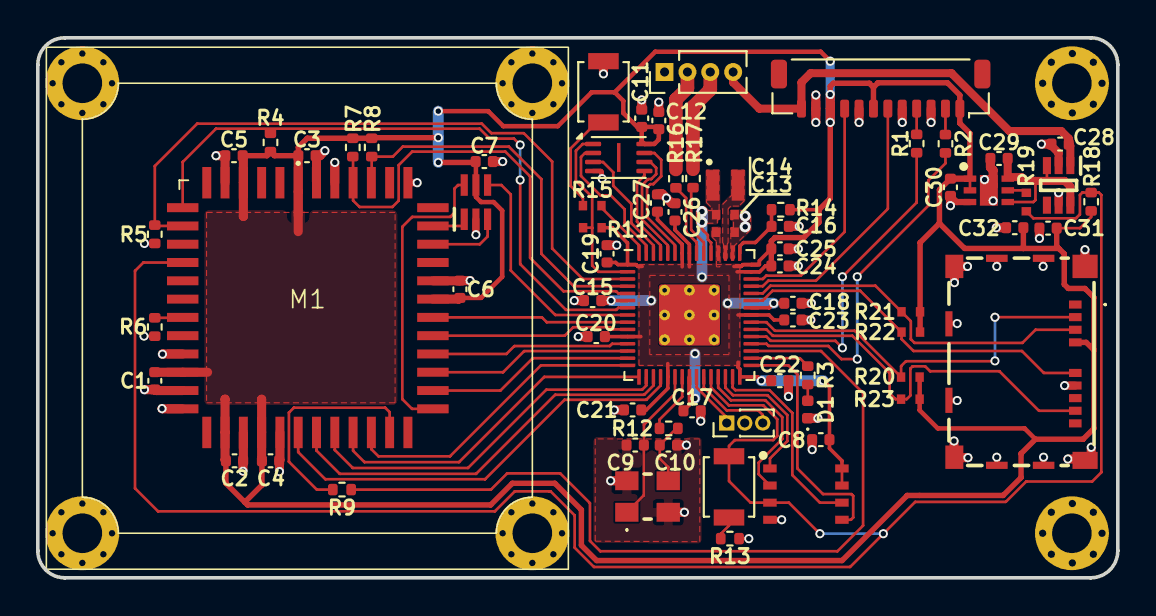
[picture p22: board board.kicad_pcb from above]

Board: 2 copper layers, 60.0 x 30.0 mm, 73 parts (0 on the bottom side), 64 nets.

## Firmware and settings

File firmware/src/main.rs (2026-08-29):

#![no_std]
#![no_main]

mod fram;
mod psram;
mod sdmmc;
mod sensor;
mod tiff;

use core::panic::PanicInfo;
use embedded_hal::{delay::DelayNs, digital::OutputPin};
use embedded_hal_bus::spi::ExclusiveDevice;
use rp235x_hal::{
    self as hal, Clock, Timer,
    clocks::StoppableClock,
    dma::{DMAExt, single_buffer},
    fugit::RateExtU32,
    gpio::{self, FunctionI2C, PinState},
    pio::PIOExt,
    timer::CopyableTimer0,
};

const NUMBER_OF_PIXELS: usize = (sensor::WIDTH as usize + 2) * sensor::HEIGHT as usize;
const U32_IMAGE_BUFFER_LENGTH: usize = NUMBER_OF_PIXELS * 10 / 32;

#[unsafe(link_section = ".start_block")]
#[used]
pub static IMAGE_DEF: hal::block::ImageDef = hal::block::ImageDef::secure_exe();

#[hal::entry]
fn main() -> ! {
    let mut p = hal::pac::Peripherals::take().unwrap();
    let mut watchdog = hal::Watchdog::new(p.WATCHDOG);
    let mut clocks = hal::clocks::init_clocks_and_plls(
        12_000_000u32,
        p.XOSC,
        p.CLOCKS,
        p.PLL_SYS,
        p.PLL_USB,
        &mut p.RESETS,
        &mut watchdog,
    )
    .unwrap();
    let mut timer = hal::Timer::new_timer0(p.TIMER0, &mut p.RESETS, &clocks);
    let sio = hal::Sio::new(p.SIO);
    let pins = gpio::Pins::new(p.IO_BANK0, p.PADS_BANK0, sio.gpio_bank0, &mut p.RESETS);

    let mut status_led = pins.gpio20.into_push_pull_output();

    // PSRAM setup
    // tPU >= 150us...
    timer.delay_us(300);
    let _cs = pins.gpio0.into_function::<gpio::FunctionXipCs1>();
    let (_, kgd, _) = psram::read_id(&p.QMI);
    if kgd != 0x5D {
        blink(&mut timer, &mut status_led, 3);
        panic!("cannot init psram");
    }
    psram::init(&p.QMI, &mut timer, clocks.system_clock.freq().to_Hz());
    // Make PSRAM writable
    p.XIP_CTRL.ctrl().modify(|_, w| w.writable_m1().set_bit());
    let psram_base =
        unsafe { core::slice::from_raw_parts_mut(psram::BASE_ADDRESS as *mut u8, 1024 * 1024 * 8) };

    // FRAM
    let mut fram_cs = pins.gpio17.into_push_pull_output();
    fram_cs.set_high();
    let fram_spi_rx = pins.gpio16.into_function::<gpio::FunctionSpi>();
    let fram_spi_sclk = pins.gpio18.into_function::<gpio::FunctionSpi>();
    let fram_spi_tx = pins.gpio19.into_function::<gpio::FunctionSpi>();
    let fram_spi =
        hal::spi::Spi::<_, _, _, 8>::new(p.SPI0, (fram_spi_tx, fram_spi_rx, fram_spi_sclk));
    let fram_spi = fram_spi.init(
        &mut p.RESETS,
        clocks.peripheral_clock.freq(),
        24.MHz(),
        embedded_hal::spi::MODE_0,
    );
    let mut fram = fram::FM25L16B::new(fram_cs, fram_spi);

    // Sensor
    let sensor_standby = pins.gpio4.into_push_pull_output_in_state(PinState::Low);
    let sensor_trigger = pins.gpio1.into_push_pull_output_in_state(PinState::Low);
    let _sensor_clock = pins.gpio21.into_function::<gpio::FunctionClock>();
    clocks
        .gpio_output0_clock
        .configure_clock(&clocks.system_clock, sensor::FREQUENCY.Hz())
        .unwrap();
    clocks.gpio_output0_clock.enable();
    let sensor_i2c_sda: gpio::Pin<_, FunctionI2C, _> = pins.gpio2.reconfigure();
    let sensor_i2c_scl: gpio::Pin<_, FunctionI2C, _> = pins.gpio3.reconfigure();
    let sensor_i2c = hal::I2C::i2c1(
        p.I2C1,
        sensor_i2c_sda,
        sensor_i2c_scl,
        100.kHz(),
        &mut p.RESETS,
        &clocks.system_clock,
    );
    let mut sensor = sensor::Sensor::new(
        clocks.gpio_output0_clock,
        timer,
        sensor_i2c,
        sensor_standby,
        sensor_trigger,
    );
    if sensor.init().is_err() {
        blink(&mut timer, &mut status_led, 5);
        panic!("cannot initialize the sensor");
    }

    // Sensor PIO
    let pio_capture = pio::pio_file!(
        "src/main.pio",
        select_program("transfer"),
        options(max_program_size = 32)
    );
    let (mut pio, sm0, _, _, _) = p.PIO0.split(&mut p.RESETS);
    let installed_program = pio.install(&pio_capture.program).unwrap();
    let sensor_d0: gpio::Pin<_, gpio::FunctionPio0, _> = pins.gpio6.into_function();
    let sensor_d1: gpio::Pin<_, gpio::FunctionPio0, _> = pins.gpio7.into_function();
    let sensor_d2: gpio::Pin<_, gpio::FunctionPio0, _> = pins.gpio8.into_function();
    let sensor_d3: gpio::Pin<_, gpio::FunctionPio0, _> = pins.gpio9.into_function();
    let sensor_d4: gpio::Pin<_, gpio::FunctionPio0, _> = pins.gpio10.into_function();
    let sensor_d5: gpio::Pin<_, gpio::FunctionPio0, _> = pins.gpio11.into_function();
    let sensor_d6: gpio::Pin<_, gpio::FunctionPio0, _> = pins.gpio12.into_function();
    let sensor_d7: gpio::Pin<_, gpio::FunctionPio0, _> = pins.gpio13.into_function();
    let sensor_d8: gpio::Pin<_, gpio::FunctionPio0, _> = pins.gpio14.into_function();
    let sensor_d9: gpio::Pin<_, gpio::FunctionPio0, _> = pins.gpio15.into_function();
    let sensor_pixel_valid: gpio::Pin<_, gpio::FunctionPio0, _> = pins.gpio5.into_function();
    let (mut sm, rx, _) = hal::pio::PIOBuilder::from_installed_program(installed_program)
        .in_pin_base(sensor_d0.id().num)
        .in_count(10)
        .clock_divisor_fixed_point(1, 0)
        .buffers(rp235x_hal::pio::Buffers::OnlyRx)
        .push_threshold(0)
        .in_shift_direction(rp235x_hal::pio::ShiftDirection::Right)
        .out_shift_direction(rp235x_hal::pio::ShiftDirection::Right)
        .autopush(true)
        .build(sm0);
    sm.set_pindirs([
        (sensor_d0.id().num, hal::pio::PinDir::Input),
        (sensor_d1.id().num, hal::pio::PinDir::Input),
        (sensor_d2.id().num, hal::pio::PinDir::Input),
        (sensor_d3.id().num, hal::pio::PinDir::Input),
        (sensor_d4.id().num, hal::pio::PinDir::Input),
        (sensor_d5.id().num, hal::pio::PinDir::Input),
        (sensor_d6.id().num, hal::pio::PinDir::Input),
        (sensor_d7.id().num, hal::pio::PinDir::Input),
        (sensor_d8.id().num, hal::pio::PinDir::Input),
        (sensor_d9.id().num, hal::pio::PinDir::Input),
        (sensor_pixel_valid.id().num, hal::pio::PinDir::Input),
    ]);

    // Sensor to PSRAM transfer (DMA)
    let (_, u32_slice, _) = unsafe { psram_base.align_to_mut::<u32>() };
    let image_buf: &mut [u32] = &mut u32_slice[..U32_IMAGE_BUFFER_LENGTH];
    let dma = p.DMA.split(&mut p.RESETS);
    let mut transfer = single_buffer::Config::new(dma.ch1, rx, image_buf);

    // SDMMC and file system setup
    let sdmmc_spi_rx = pins.gpio24.into_function::<hal::gpio::FunctionSpi>();
    let sdmmc_spi_cs = pins.gpio25.into_push_pull_output();
    let sdmmc_spi_sclk = pins.gpio26.into_function::<hal::gpio::FunctionSpi>();
    let sdmmc_spi_tx = pins.gpio27.into_function::<hal::gpio::FunctionSpi>();
    let sdmmc_spi_bus =
        hal::spi::Spi::<_, _, _, 8>::new(p.SPI1, (sdmmc_spi_tx, sdmmc_spi_rx, sdmmc_spi_sclk));
    let sdmmc_spi_bus = sdmmc_spi_bus.init(
        &mut p.RESETS,
        clocks.peripheral_clock.freq(),
        24.MHz(),
        embedded_hal::spi::MODE_0,
    );
    let sdmmc_spi_bus = ExclusiveDevice::new_no_delay(sdmmc_spi_bus, sdmmc_spi_cs)
        .expect("Failed to create SPI device");

    let mut sdmmc_memory = sdmmc::Sdmmc::new(sdmmc_spi_bus, &mut timer);

    // Capture frame...
    for denominator in (24..=25).step_by(20) {
        sm.clear_fifos();
        let running_sm = sm.start();
        transfer.bswap(false);
        let running_transfer = transfer.start();

        status_led.set_high().unwrap();
        let capture_result = sensor.configure_and_capture(1f32, (1, denominator), || {
            let (channel, from, to) = running_transfer.wait();
            let stopped_sm = running_sm.stop();
            (stopped_sm, (channel, from, to))
        });
        status_led.set_low().unwrap();

        (sm, transfer) = if let Ok((returned_sm, (channel, from, to))) = capture_result {
            let image_counter = if let Ok(v) = fram.read(0).and_then(|v: u64| {
                fram.write(0, v.wrapping_add(1))?;
                Ok(v)
            }) {
                v
            } else {
                blink(&mut timer, &mut status_led, 4);
                panic!("cannot read or incrament image counter");
            };
            let image_counter = (image_counter % u16::MAX as u64) as u16;

            let (_, image, _) = unsafe { to.align_to_mut::<u8>() };
            if sdmmc_memory
                .write_image(image_counter, sensor::WIDTH + 2, sensor::HEIGHT, 10, image)
                .is_err()
            {
                blink(&mut timer, &mut status_led, 6);
                panic!("cannot save image");
            }

            (returned_sm, single_buffer::Config::new(channel, from, to))
        } else {
            blink(&mut timer, &mut status_led, 7);
            panic!("cannot capture frame");
        };
    }

    loop {
        let _ = status_led.set_high();
        timer.delay_ms(50);
        let _ = status_led.set_low();
        timer.delay_ms(50);
    }
}

fn blink<OP: OutputPin>(timer: &mut Timer<CopyableTimer0>, led: &mut OP, n: u8) {
    for _ in 0..n {
        let _ = led.set_high();
        timer.delay_ms(400);
        let _ = led.set_low();
        timer.delay_ms(400);
    }
}

#[inline(never)]
#[panic_handler]
fn panic(_info: &PanicInfo) -> ! {
    loop {}
}

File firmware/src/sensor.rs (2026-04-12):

use embedded_hal::{delay::DelayNs, digital::OutputPin, i2c::I2c};
use rp235x_hal::{
    Timer,
    clocks::{GpioOutput0Clock, StoppableClock},
    timer::CopyableTimer0,
};

use mt9m001::MT9M001;

pub const HEIGHT: u16 = 1048;
pub const WIDTH: u16 = 1310;
pub const FREQUENCY: u32 = 6_500_000;

pub struct Sensor<I2C: I2c, SP: OutputPin, TP: OutputPin> {
    sensor_clock: GpioOutput0Clock,
    timer: Timer<CopyableTimer0>,
    standby: SP,
    trigger: TP,
    mt9m001: MT9M001<I2C>,
}

impl<I2C, SP, TP> Sensor<I2C, SP, TP>
where
    I2C: I2c,
    SP: OutputPin,
    TP: OutputPin,
{
    pub fn new(
        sensor_clock: GpioOutput0Clock,
        timer: Timer<CopyableTimer0>,
        i2c: I2C,
        standby: SP,
        trigger: TP,
    ) -> Self {
        Self {
            sensor_clock,
            timer,
            standby,
            trigger,
            mt9m001: MT9M001::new(i2c),
        }
    }

    fn wake(&mut self) -> Result<(), SensorError> {
        self.sensor_clock.enable();
        self.standby
            .set_low()
            .map_err(|_| SensorError::StandbyError)?;
        let output_control = mt9m001::OutputControl::DEFAULT.set_chip_enable(true);
        self.mt9m001
            .set_output_control(&output_control)
            .map_err(|_| SensorError::Spi)?;
        self.timer.delay_ms(1);
        Ok(())
    }

    fn sleep(&mut self) -> Result<(), SensorError> {
        let output_control = mt9m001::OutputControl::DEFAULT.set_chip_enable(false);
        self.mt9m001
            .set_output_control(&output_control)
            .map_err(|_| SensorError::Spi)?;
        self.timer.delay_ms(1);
        self.standby
            .set_high()
            .map_err(|_| SensorError::StandbyError)?;
        self.sensor_clock.disable();
        Ok(())
    }

    pub fn init(&mut self) -> Result<(), SensorError> {
        self.wake()?;

        self.mt9m001.set_reset(1).map_err(|_| SensorError::Spi)?;
        self.mt9m001.set_reset(0).map_err(|_| SensorError::Spi)?;

        let read_options_1 = mt9m001::ReadOptions1::DEFAULT.set_snapshot_mode(true);
        self.mt9m001
            .set_read_options_1(&read_options_1)
            .map_err(|_| SensorError::Spi)?;

        let cal_control =
            mt9m001::CalCtrl::DEFAULT.set_manual_override_of_black_level_correction(true);
        self.mt9m001
            .set_cal_ctrl(&cal_control)
            .map_err(|_| SensorError::Spi)?;

        //let read_options_2 = mt9m001::ReadOptions2::DEFAULT.set_raw_data_output_mode(true);
        //self.mt9m001.set_read_options_2(&read_options_2)?;

        self.mt9m001
            .set_column_start(0)
            .map_err(|_| SensorError::Spi)?;
        self.mt9m001
            .set_column_size(WIDTH)
            .map_err(|_| SensorError::Spi)?;
        self.mt9m001
            .set_row_start(0)
            .map_err(|_| SensorError::Spi)?;
        self.mt9m001
            .set_row_size(HEIGHT)
            .map_err(|_| SensorError::Spi)?;
        self.mt9m001
            .set_horizontal_blanking(0)
            .map_err(|_| SensorError::Spi)?;
        self.mt9m001
            .set_vertical_blanking(0)
            .map_err(|_| SensorError::Spi)?;

        self.sleep()?;

        Ok(())
    }

    pub fn configure_and_capture<T, F: FnOnce() -> T>(
        &mut self,
        gain: f32,
        shutter: (u32, u32),
        transfer_fn: F,
    ) -> Result<T, SensorError> {
        self.wake()?;

        // Set gain
        let gain = if gain <= 4f32 {
            0x0008 + ((gain - 1f32) / 0.125f32) as u16
        } else if gain <= 8f32 {
            0x0051 + ((gain - 4f32) / 0.25f32) as u16
        } else {
            0x0061 + ((gain - 9f32) / 1.0) as u16
        };
        self.mt9m001
            .set_global_gain(gain)
            .map_err(|_| SensorError::Spi)?;

        // Set shutter speed
        let shutter_delay = self
            .mt9m001
            .get_shutter_delay()
            .map_err(|_| SensorError::Spi)?;
        let col_size = self
            .mt9m001
            .get_column_size()
            .map_err(|_| SensorError::Spi)?;
        let horizontal_blanking = self
            .mt9m001
            .get_horizontal_blanking()
            .map_err(|_| SensorError::Spi)?;
        let (numerator, denominator) = shutter;
        let integration_time_in_clock_periods = (numerator * FREQUENCY) / denominator;
        let shutter_width = (integration_time_in_clock_periods + 180 + 4 * shutter_delay as u32)
            / (col_size as u32 + horizontal_blanking as u32 + 226);
        self.mt9m001
            .set_shutter_width(shutter_width as u16)
            .map_err(|_| SensorError::Spi)?;

        // Trigger...
        self.trigger
            .set_high()
            .map_err(|_| SensorError::TriggerError)?;
        self.trigger
            .set_low()
            .map_err(|_| SensorError::TriggerError)?;

        // Capture here...
        let result = transfer_fn();

        self.sleep()?;

        Ok(result)
    }
}

#[derive(Debug)]
pub enum SensorError {
    Spi,
    TriggerError,
    StandbyError,
}

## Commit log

2026-01-11 use embassy, implement minor script improvements, and make minor pcb improvements
    [board.kicad_pcb]
2026-02-28 switch back to rp235x-hal from embassy
2026-02-28 fix sensor frequency bug and improve README.md
    [main.rs, sensor.rs]
2026-03-13 indicate sensor to psram transfer
2026-04-12 kicad 10.0
    [board.kicad_pcb]
2026-04-14 improve tiff implementation and fix pio program name bug
    [main.rs]
2026-07-12 add lens mount datasheet

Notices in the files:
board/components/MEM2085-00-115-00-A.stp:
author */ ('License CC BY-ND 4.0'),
